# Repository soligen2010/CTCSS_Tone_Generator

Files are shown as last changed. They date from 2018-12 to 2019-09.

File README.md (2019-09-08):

# CTCSS_Tone_Generator

 This program is generates CTCSS tones.

 Circuit info:
 The output is PWM and must be passed though low pass filters (I used 2 RC filters) to create a sine wave, then buffered with an op amp, followed by a 
 10k trim put to set the final output level.
 
 Suggested filter cut-off frequency is 300Hz
 
 Frequency response can be flattened by adjusting variables in the generateSineWave() procedure.

 Copyright 2018 by Dennis Cabell
 KE8FZX
 
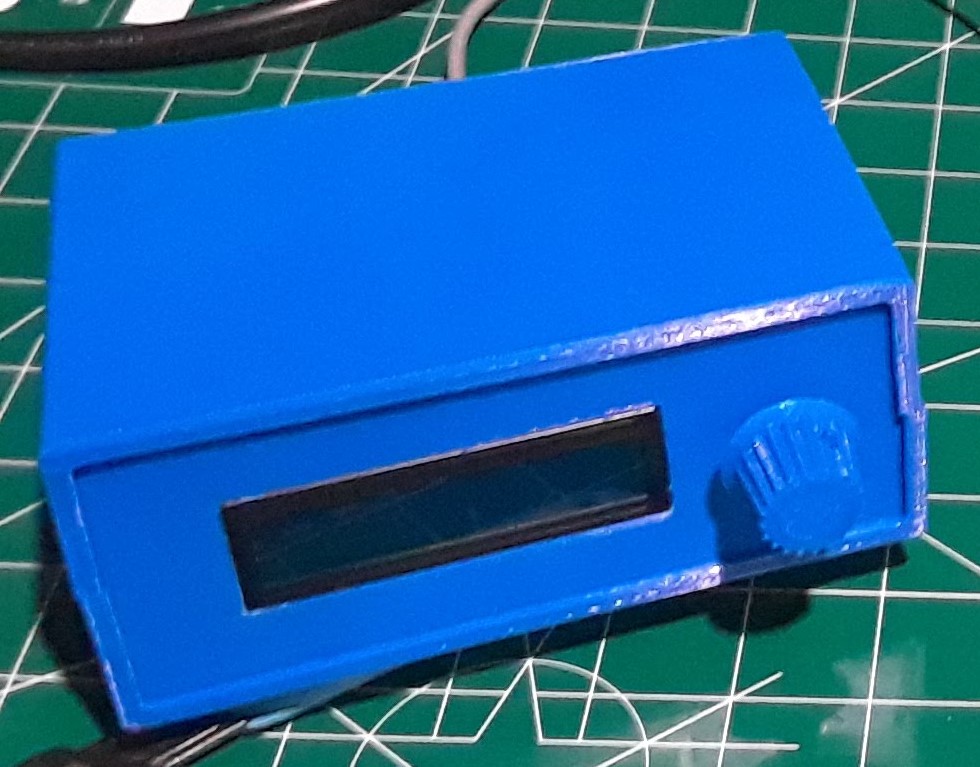
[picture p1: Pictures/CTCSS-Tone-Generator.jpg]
 
 
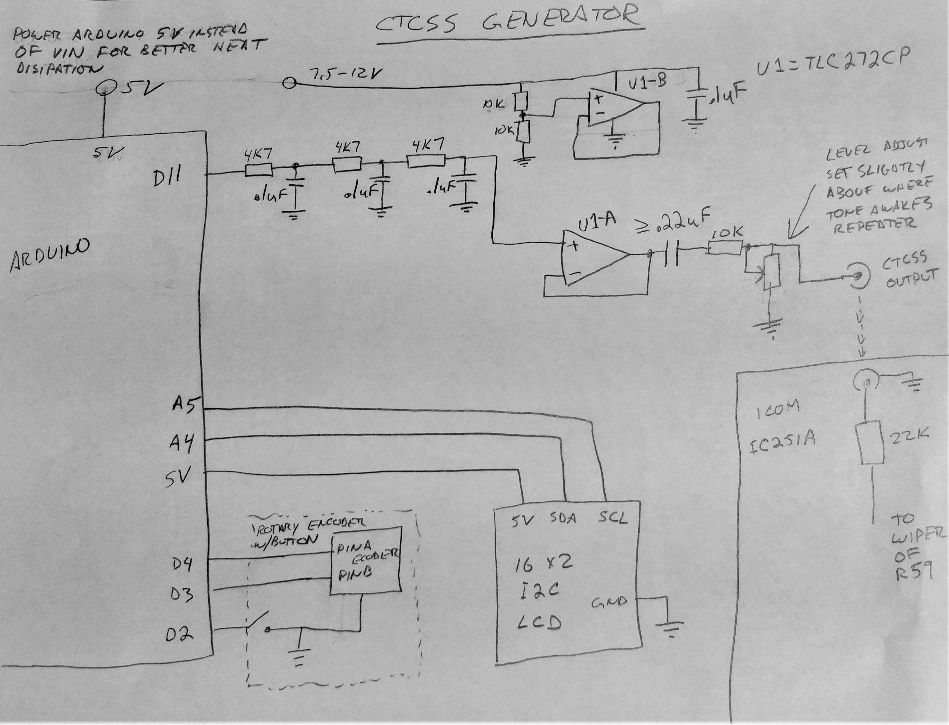
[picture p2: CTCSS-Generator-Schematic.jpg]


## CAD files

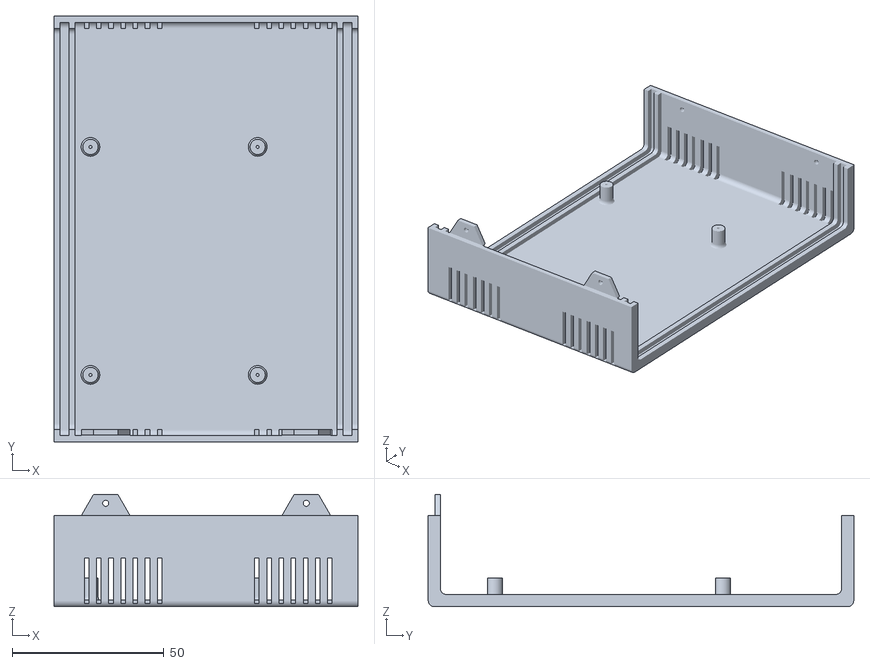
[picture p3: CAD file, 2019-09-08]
Case/CTCSS_TONE_GENERATOR.stl
100.0 x 140.0 x 36.9

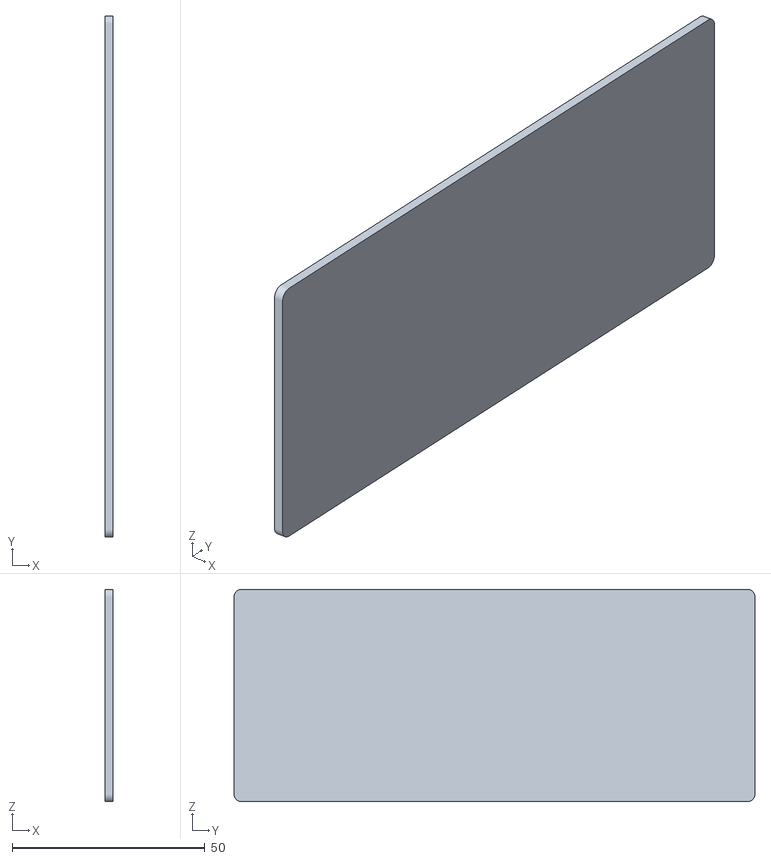
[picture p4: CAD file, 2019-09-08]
Case/CTCSS_TONE_GENERATOR Panel.stl
2.00 x 135.1 x 55.1

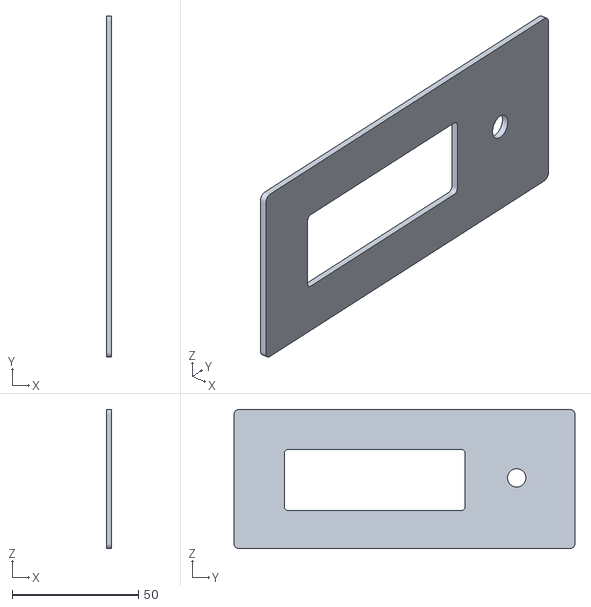
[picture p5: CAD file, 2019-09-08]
Case/CTCSS_TONE_GENERATOR Panel front.stl
2.00 x 135.1 x 55.1

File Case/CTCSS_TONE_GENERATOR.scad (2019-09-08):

/*//////////////////////////////////////////////////////////////////
              -    FB Aka Heartman/Hearty 2016     -                   
              -   http://heartygfx.blogspot.com    -                  
              -       OpenScad Parametric Box      -                     
              -         CC BY-NC 3.0 License       -                      
////////////////////////////////////////////////////////////////////                                                                                                             
12/02/2016 - Fixed minor bug 
28/02/2016 - Added holes ventilation option                    
09/03/2016 - Added PCB feet support, fixed the shell artefact on export mode. 

*/////////////////////////// - Info - //////////////////////////////

// All coordinates are starting as integrated circuit pins.
// From the top view :

//   CoordD           <---       CoordC
//                                 ^
//                                 ^
//                                 ^
//   CoordA           --->       CoordB


////////////////////////////////////////////////////////////////////


////////// - Paramètres de la boite - Box parameters - /////////////

/* [Box dimensions] */
// - Longueur - Length  
  Length        = 100;       
// - Largeur - Width
  Width         = 140;                     
// - Hauteur - Height  
  Height        = 60;  
// - Epaisseur - Wall thickness  
  Thick         = 2;//[2:5]  
  
/* [Box options] */
// - Diamètre Coin arrondi - Filet diameter  
  Filet         = 2;//[0.1:12] 
// - lissage de l'arrondi - Filet smoothness  
  Resolution    = 50;//[1:100] 
// - Tolérance - Tolerance (Panel/rails gap)
  m             = 0.9;
// Pieds PCB - PCB feet (x4) 
  PCBFeet       = 0;// [0:No, 1:Yes]
// - Decorations to ventilation holes
  Vent          = 1;// [0:No, 1:Yes]
// - Decoration-Holes width (in mm)
  Vent_width    = 1.5;   


  
/* [PCB_Feet] */
//All dimensions are from the center foot axis

// - Coin bas gauche - Low left corner X position
PCBPosX         = -1;
// - Coin bas gauche - Low left corner Y position
PCBPosY         =  10;
// - Longueur PCB - PCB Length
PCBLength       = 55;
// - Largeur PCB - PCB Width
PCBWidth        = 75;
// - Heuteur pied - Feet height
FootHeight      = 10;
// - Diamètre pied - Foot diameter
FootDia         = 5;
// - Diamètre trou - Hole diameter
FootHole        = 2;  
  

/* [STL element to export] */
//Coque haut - Top shell
TShell          = 0;// [0:No, 1:Yes]
//Coque bas- Bottom shell
BShell          = 0;// [0:No, 1:Yes]
//Panneau avant - Front panel
FPanL           = 1;// [0:No, 1:Yes]
//Panneau arrière - Back panel  
BPanL           = 0;// [0:No, 1:Yes]


  
/* [Hidden] */
// - Couleur coque - Shell color  
Couleur1        = "Orange";       
// - Couleur panneaux - Panels color    
Couleur2        = "OrangeRed";    
// Thick X 2 - making decorations thicker if it is a vent to make sure they go through shell
Dec_Thick       = Vent ? Thick*2 : Thick; 
// - Depth decoration
Dec_size        = Vent ? Thick*2 : 0.8;





/////////// - Boitier générique bord arrondis - Generic rounded box - //////////

module RoundBox($a=Length, $b=Width, $c=Height){// Cube bords arrondis
                    $fn=Resolution;            
                    translate([0,Filet,Filet]){  
                    minkowski (){                                              
                        cube ([$a-(Length/2),$b-(2*Filet),$c-(2*Filet)], center = false);
                        rotate([0,90,0]){    
                        cylinder(r=Filet,h=Length/2, center = false);
                            } 
                        }
                    }
                }// End of RoundBox Module

      
////////////////////////////////// - Module Coque/Shell - //////////////////////////////////         

module Coque(){//Coque - Shell  
    Thick = Thick*2;  
    difference(){    
        difference(){//sides decoration
            union(){    
                     difference() {//soustraction de la forme centrale - Substraction Fileted box
                      
                        difference(){//soustraction cube median - Median cube slicer
                            union() {//union               
                            difference(){//Coque    
                                RoundBox();
                                translate([Thick/2,Thick/2,Thick/2]){     
                                        RoundBox($a=Length-Thick, $b=Width-Thick, $c=Height-Thick);
                                        }
                                        }//Fin diff Coque                            
                                difference(){//largeur Rails        
                                     translate([Thick+m,Thick/2,Thick/2]){// Rails
                                          RoundBox($a=Length-((2*Thick)+(2*m)), $b=Width-Thick, $c=Height-(Thick*2));
                                                          }//fin Rails
                                     translate([((Thick+m/2)*1.55),Thick/2,Thick/2+0.1]){ // +0.1 added to avoid the artefact
                                          RoundBox($a=Length-((Thick*3)+2*m), $b=Width-Thick, $c=Height-Thick);
                                                    }           
                                                }//Fin largeur Rails
                                    }//Fin union                                   
                               translate([-Thick,-Thick,Height/2]){// Cube à soustraire
                                    cube ([Length+100, Width+100, Height], center=false);
                                            }                                            
                                      }//fin soustraction cube median - End Median cube slicer
                               translate([-Thick/2,Thick,Thick]){// Forme de soustraction centrale 
                                    RoundBox($a=Length+Thick, $b=Width-Thick*2, $c=Height-Thick);       
                                    }                          
                                }                                          


                difference(){// wall fixation box legs
                    union(){
                        translate([3*Thick +5,Thick,Height/2]){
                            rotate([90,0,0]){
                                    $fn=6;
                                    cylinder(d=16,Thick/2);
                                    }   
                            }
                            
                       translate([Length-((3*Thick)+5),Thick,Height/2]){
                            rotate([90,0,0]){
                                    $fn=6;
                                    cylinder(d=16,Thick/2);
                                    }   
                            }

                        }
                            translate([4,Thick+Filet,Height/2-57]){   
                             rotate([45,0,0]){
                                   cube([Length,40,40]);    
                                  }
                           }
                           translate([0,-(Thick*1.46),Height/2]){
                                cube([Length,Thick*2,10]);
                           }
                    } //Fin fixation box legs
            }

        union(){// outbox sides decorations
            
            for(i=[0:Thick:Length/4]){

                // Ventilation holes part code submitted by Ettie - Thanks ;) 
                    translate([10+i,-Dec_Thick+Dec_size,1]){
                    cube([Vent_width,Dec_Thick,Height/4]);
                    }
                    translate([(Length-10) - i,-Dec_Thick+Dec_size,1]){
                    cube([Vent_width,Dec_Thick,Height/4]);
                    }
                    translate([(Length-10) - i,Width-Dec_size,1]){
                    cube([Vent_width,Dec_Thick,Height/4]);
                    }
                    translate([10+i,Width-Dec_size,1]){
                    cube([Vent_width,Dec_Thick,Height/4]);
                    }
  
                
                    }// fin de for
               // }
                }//fin union decoration
            }//fin difference decoration
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

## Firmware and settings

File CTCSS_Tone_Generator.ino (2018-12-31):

/*
 Copyright 2018 by Dennis Cabell
 KE8FZX

 This program is generates CTCSS tones.

# CTCSS_Tone_Generator

 This program is generates CTCSS tones.

 Circuit info:
 The output is PWM and must be passed though low pass filters (I used 2 RC filters) to create a sine wave, then buffered with an op amp, followed by a 
 10k trim put to set the final output level.
 
 Suggested filter cut-off frequency is 300Hz
 
 Frequency response can be flattened by adjusting variables in the generateSineWave() procedure.


 The Rotary Encoder files are attributed to the original authors.  Please see those files for 
 more information
 
 * The Timer2 setup and interrupt routines are from following source.  Copyright for these parts is 
 * by the original author.
 * DDS Sine Generator mit ATMEGS 168
 * Timer2 generates the  31250 KHz Clock Interrupt
 *
 * KHM 2009 /  Martin Nawrath
 * Kunsthochschule fuer Medien Koeln
 * Academy of Media Arts Cologne

 
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

 */
#include "RotaryEncoder.h"

#define ENCODER_PINA     3
#define ENCODER_PINB     4
#define ENCODER_BTN      2

  #include <LiquidCrystal_I2C.h>

  #define LCD_I2C_ADDR     0x3F
  //#define LCD_I2C_ADDR     0x27
  #define I2C_EN_PIN              2
  #define I2C_RW_PIN              1
  #define I2C_RS_PIN              0
  #define I2C_D4_PIN              4
  #define I2C_D5_PIN              5
  #define I2C_D6_PIN              6
  #define I2C_D7_PIN              7
  #define I2C_BL_PIN              3   //Back light
  #define I2C_BACKLIGHT_POLARITY  POSITIVE
  
  LiquidCrystal_I2C lcd(LCD_I2C_ADDR,   // Set the LCD I2C address
                        I2C_EN_PIN,
                        I2C_RW_PIN,
                        I2C_RS_PIN,
                        I2C_D4_PIN,
                        I2C_D5_PIN,
                        I2C_D6_PIN,
                        I2C_D7_PIN,
                        I2C_BL_PIN,
                        I2C_BACKLIGHT_POLARITY);  

#include "avr/pgmspace.h"

// table of 256 sine values / one sine period
volatile byte sine256[256];

// table of ctcss frequencies / stored in flash memory
const float ctcssFrequencies[]  = {
                67, 69.3, 71, 71.9, 74.4, 77, 79.7, 82.5, 85.4, 88.5,
                91.5, 94.8, 97.4, 100, 103.5, 107.2, 110.9, 114.8, 118.8, 123,
                127.3, 131.8, 136.5, 141.3, 146.2, 151.4, 156.7, 159.8, 162.2, 165.5,
                167.9, 171.3, 173.8, 177.3, 179.9, 183.5, 186.2, 189.9, 192.8, 196.6,
                199.5, 203.5, 206.5, 210.7, 218.1, 225.7, 229.1, 233.6, 241.8, 250.3,
                254.1};
const int maxFrequencyIndex = 50;

int frequenceIndex = 13;
                
#define cbi(sfr, bit) (_SFR_BYTE(sfr) &= ~_BV(bit))
#define sbi(sfr, bit) (_SFR_BYTE(sfr) |= _BV(bit))

double dfreq = ctcssFrequencies[frequenceIndex];
volatile bool on_off_state = true;
 const double refclk=31372.549;  // =16MHz / 510   -- Raise this number to lower frequency
//const double refclk=31076.6;      // measured
//const double refclk=30976.6;      // measured

// variables used inside interrupt service declared as voilatile
volatile byte c4ms = 255;              // counter incremented all 4ms
volatile unsigned long phaccu;   // pahse accumulator
volatile unsigned long tword_m;  // dds tuning word m

// Setup a RoraryEncoder for pins A2 and A3:
RotaryEncoder encoder2(ENCODER_PINB, ENCODER_PINA);

void setup()
{
  //Serial.begin(74880);
  pinMode(ENCODER_PINA, INPUT_PULLUP);
  pinMode(ENCODER_PINB, INPUT_PULLUP);
  pinMode(ENCODER_BTN, INPUT_PULLUP);
  pinMode(11, OUTPUT);     // pin11= PWM  output / frequency output

  encoder2.setPosition(frequenceIndex);

  lcd.begin(16, 2);
  lcd.clear();
  lcd.setCursor(0, 0);lcd.print(F("CTCSS GENERATOR"));

  generateSineWave(dfreq);

  Setup_timer2();

  // disable interrupts to avoid timing distortion
  cbi (TIMSK0,TOIE0);              // disable Timer0 !!! delay() is now not available
  sbi (TIMSK2,TOIE2);              // enable Timer2 Interrupt
  
  tword_m=pow(2,32)*dfreq/refclk;  // calulate DDS new tuning word 
  
  PCICR |= (1 << PCIE2);    // This enables Pin Change Interrupt 2 that covers Port D.
  PCMSK2 |= (1 << PCINT19) | (1 << PCINT20);  // This enables the interrupt for pin 2 and 3 of Port D.
}

void loop()
{
  while(1) {
    static double old_dfreq = -1;
    if (c4ms >= 10) {                 // timer / wait for debounce
      c4ms = 0;
      
      static int prevFrequenceIndex = 0;
      frequenceIndex = encoder2.getPosition();
      if (frequenceIndex != prevFrequenceIndex) {
        frequenceIndex = constrain(frequenceIndex,0,maxFrequencyIndex);
        encoder2.setPosition(frequenceIndex);
        if (frequenceIndex != prevFrequenceIndex) {
          prevFrequenceIndex = frequenceIndex;
          dfreq = ctcssFrequencies[frequenceIndex];
          //value = 0;
          cbi (TIMSK2,TOIE2);              // disble Timer2 Interrupt
          generateSineWave(dfreq);
          tword_m=pow(2,32)*dfreq/refclk;  // calulate DDS new tuning word 
          sbi (TIMSK2,TOIE2);              // enable Timer2 Interrupt 
        }
      }  
      if (old_dfreq != dfreq) {
        lcd.setCursor(0, 1);lcd.print("       ");
        lcd.setCursor(0, 1);lcd.print(dfreq,1); 
        old_dfreq = dfreq;     
      }
      checkButton();
    }
  }
}

void checkButton() {
  static bool old_on_off_state = !on_off_state;
  static bool buttonDown = false;
  static byte PrevButtonState = HIGH;
  
  byte buttonState = digitalRead(ENCODER_BTN);

  if ((buttonState == HIGH) && buttonDown)   {    // make sure button was down at leasst 1 full cycle before registering click
    on_off_state = !on_off_state;
    buttonDown = false;    
  } 
  if ((buttonState == LOW) && PrevButtonState == LOW) {
    buttonDown = true;
  }
  PrevButtonState = buttonState;
  
  if (old_on_off_state != on_off_state) {
    if (on_off_state) {
      lcd.setCursor(12, 1);lcd.print(" ON ");  
    } else {
      lcd.setCursor(12, 1);lcd.print("OFF ");
    }
    old_on_off_state = on_off_state;     
  }  
}

//******************************************************************
// timer2 setup
// set prscaler to 1, PWM mode to phase correct PWM,  16000000/510 = 31372.55 Hz clock
void Setup_timer2() {

// Timer2 Clock Prescaler to : 1
  sbi (TCCR2B, CS20);
  cbi (TCCR2B, CS21);
  cbi (TCCR2B, CS22);

  // Timer2 PWM Mode set to Phase Correct PWM
  cbi (TCCR2A, COM2A0);  // clear Compare Match
  sbi (TCCR2A, COM2A1);

  sbi (TCCR2A, WGM20);  // Mode 1  / Phase Correct PWM
  cbi (TCCR2A, WGM21);
  cbi (TCCR2B, WGM22);
}

//******************************************************************
// Timer2 Interrupt Service at 31372,550 KHz = 32uSec
// this is the timebase REFCLOCK for the DDS generator
// FOUT = (M (REFCLK)) / (2 exp 32)
// runtime : 8 microseconds ( inclusive push and pop)
ISR(TIMER2_OVF_vect) {
  static byte icnt1 = 0;
  static byte icnt;

  phaccu=phaccu+tword_m; // soft DDS, phase accu with 32 bits
  icnt=phaccu >> 24;     // use upper 8 bits for phase accu as frequency information
                         // read value fron ROM sine table and send to PWM DAC
  if (on_off_state) {
    OCR2A=sine256[icnt];   
  } 

  if(icnt1++ == 31) {  // increment variable c4ms all ~1 milliseconds
    c4ms++;
    icnt1=0;
  }   
}

void generateSineWave(float freq) {

  float lowFreqAmplitude = 330;
  float HighFreqAmplitude = 120;
  float MidFreqAdjustPct = -.10;

  float lowBound = 0;
  float MaxUpBound = 255;

  float MinUpBound = HighFreqAmplitude/lowFreqAmplitude * MaxUpBound;

  float upBound = mapf(freq,ctcssFrequencies[0],ctcssFrequencies[maxFrequencyIndex],MinUpBound,MaxUpBound);

  // Take out mid freuencey hump in the response
  float midFrequence = (ctcssFrequencies[0] + ctcssFrequencies[maxFrequencyIndex]) / 2.0;  
  if  (freq < midFrequence) {
    upBound = (1 + mapf(freq,ctcssFrequencies[0],midFrequence,0,MidFreqAdjustPct)) * upBound;
  } else {
    upBound = (1 + mapf(freq,midFrequence,ctcssFrequencies[maxFrequencyIndex],MidFreqAdjustPct,0)) * upBound;
  }


  for (int x = 0; x <= 255; x++) {
      float sineValue = sin(mapf((float)x, 0.0, 256.0, 0.0, 2.0 * PI));
      sine256[x] = (byte)constrain((int)(mapf(sineValue, -1.0, 1.0, lowBound, upBound) + .5),0,255);
      //Serial.println(sine256[x]);
  }

}


float mapf(float x, float in_min, float in_max, float out_min, float out_max)
{
    return (x - in_min) * (out_max - out_min) / (in_max - in_min) + out_min;
}

// The Interrupt Service Routine for Pin Change Interrupt 2
// This routine will only be called on any signal change on 3 and 4: exactly where we need to check.
ISR(PCINT2_vect) {
  encoder2.tick(); // just call tick() to check the state.
}

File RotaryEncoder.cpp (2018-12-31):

// -----
// RotaryEncoder.cpp - Library for using rotary encoders.
// This class is implemented for use with the Arduino environment.
// Copyright (c) by Matthias Hertel, http://www.mathertel.de
// This work is licensed under a BSD style license. See http://www.mathertel.de/License.aspx
// More information on: http://www.mathertel.de/Arduino
// -----
// 18.01.2014 created by Matthias Hertel
// 17.06.2015 minor updates.
// -----

#include "Arduino.h"
#include "RotaryEncoder.h"


// The array holds the values –1 for the entries where a position was decremented,
// a 1 for the entries where the position was incremented
// and 0 in all the other (no change or not valid) cases.

const int8_t KNOBDIR[] = {
  0, -1,  1,  0,
  1,  0,  0, -1,
  -1,  0,  0,  1,
0,  1, -1,  0  };


// positions: [3] 1 0 2 [3] 1 0 2 [3]
// [3] is the positions where my rotary switch detends
// ==> right, count up
// <== left,  count down


// ----- Initialization and Default Values -----

RotaryEncoder::RotaryEncoder(int pin1, int pin2) {
  
  // Remember Hardware Setup
  _pin1 = pin1;
  _pin2 = pin2;
  
  // Setup the input pins
  pinMode(pin1, INPUT);
  digitalWrite(pin1, HIGH);   // turn on pullup resistor

  pinMode(pin2, INPUT);
  digitalWrite(pin2, HIGH);   // turn on pullup resistor

  // when not started in motion, the current state of the encoder should be 3
  _oldState = 3;

  // start with position 0;
  _position = 0;
  _positionExt = 0;
  _positionExtPrev = 0;
} // RotaryEncoder()


long  RotaryEncoder::getPosition() {
  return _positionExt;
} // getPosition()


int8_t  RotaryEncoder::getDirection() {

    int8_t ret = 0;
    
    if( _positionExtPrev > _positionExt )
    {
        ret = -1;
        _positionExtPrev = _positionExt;
    }
    else if( _positionExtPrev < _positionExt )
    {
        ret = 1;
        _positionExtPrev = _positionExt;
    }
    else 
    {
        ret = 0;
        _positionExtPrev = _positionExt;
    }        
    
    return ret;
}



void RotaryEncoder::setPosition(long newPosition) {
  // only adjust the external part of the position.
  _position = ((newPosition<<2) | (_position & 0x03L));
  _positionExt = newPosition;
  _positionExtPrev = newPosition;
} // setPosition()


void RotaryEncoder::tick(void)
{
  int sig1 = digitalRead(_pin1);
  int sig2 = digitalRead(_pin2);
  int8_t thisState = sig1 | (sig2 << 1);

  if (_oldState != thisState) {
    _position += KNOBDIR[thisState | (_oldState<<2)];
    
    if (thisState == LATCHSTATE)
      _positionExt = _position >> 2;
    
    _oldState = thisState;
  } // if
} // tick()

// End

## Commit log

2019-09-08 Added Case & Schematic
    [CTCSS_TONE_GENERATOR Panel front.stl, CTCSS_TONE_GENERATOR Panel.stl, CTCSS_TONE_GENERATOR.scad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]
2019-09-08 Link to Schematic

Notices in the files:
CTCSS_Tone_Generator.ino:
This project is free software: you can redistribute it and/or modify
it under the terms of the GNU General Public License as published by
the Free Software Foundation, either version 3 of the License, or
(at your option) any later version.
